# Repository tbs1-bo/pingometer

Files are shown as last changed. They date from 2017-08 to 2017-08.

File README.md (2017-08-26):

Zeigometer
==========

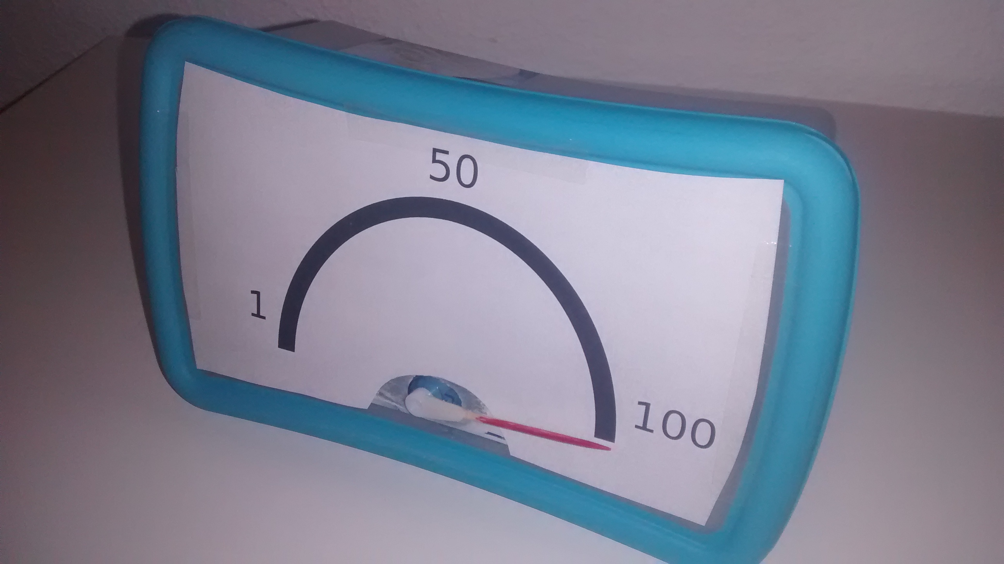
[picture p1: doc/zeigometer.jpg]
zeigometer


The zeigometer is an autonmous device that can show a value on a
scale. It can be made of a an ESP8266, a servo motor, a powerbank or battery and
some housing - I used an ice-cream package for this.

The servo motor is connected to an ESP8266, reads analog values from an
MQTT Broker and  sends the value to a servo that visualizes the value
on a scale. The project is mainly inspired by the
[pingo meter project](https://www.raspberrypi.org/magpi/pingometer/)
from the Raspberry Pi Magazine.

Process Sequence
----------------

Here is what the device actually does.

1. Power on
2. Connect to a pre-configured Wifi-AP
3. Fetch a message from an MQTT Broker from a given topic. The message
   type must be an integer value between 0 and 100. Use retained
   messages when posting to this topic such that the client receives
   older messages.
4. Adjust the needle connected to a servo motor to reflect the value -
   0=left, 100=right.
5. Go into deep sleep for some pre-configured period of time.
6. Awake and start from the beginning.

Sketch
------

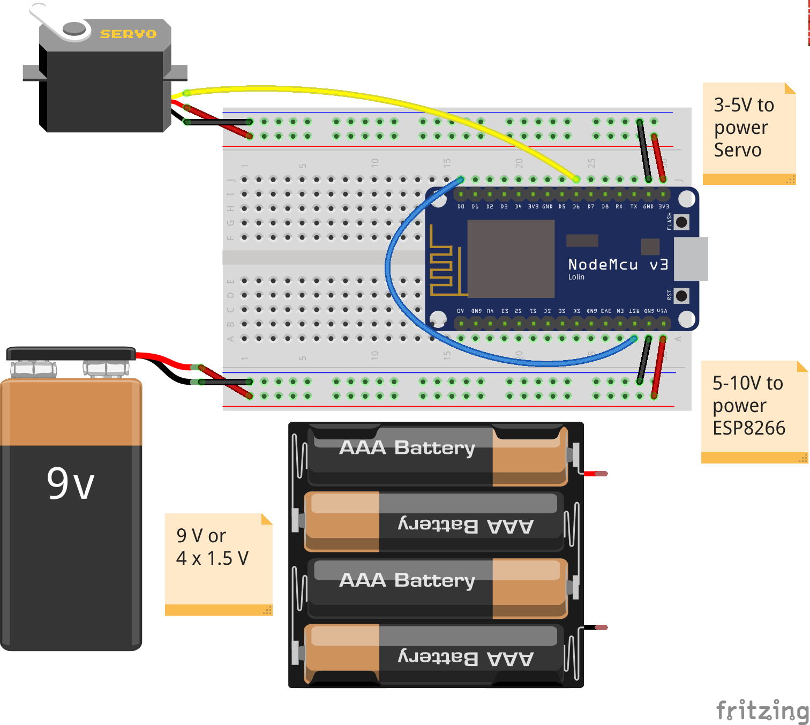
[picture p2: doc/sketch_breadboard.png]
sketch


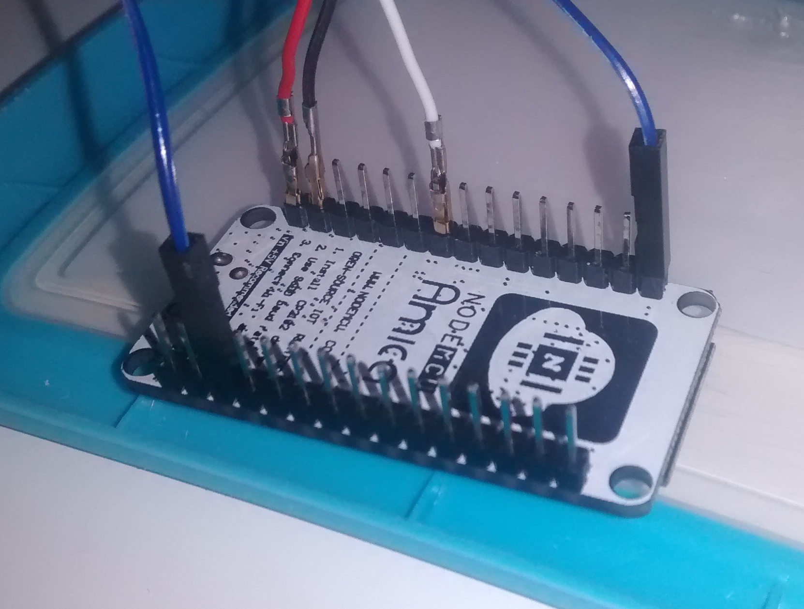
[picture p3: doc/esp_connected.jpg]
esp connected


- The servo is connected to the VCC and Ground for power supply.
- GPIO12 (or what ever is configured) is used as PWM pin for
  controlling the servo.
- GPIO16 and RESET are connected to awake the ESP8266 from deep sleep
  mode. GPIO16 is the only pin that can be used for this purpose.
- Power supply via VIN. Since this pin is controlled by a power
  regulator, up to 10V can be used.

Configuration
-------------

Move [config_sample.py](config_sample.py) to `config.py` and adjust
the values. The file contains comments that explain what the purpose
of the values.

Installation
------------

The ESP8266 needs to be
[flashed with a Micropython firmware](http://docs.micropython.org/en/latest/esp8266/esp8266/tutorial/intro.html#deploying-the-firmware).

Transfer all python files onto the ESP8266. A tool
like [ampy](https://github.com/adafruit/ampy) and
the [deploy.sh](deploy.sh) script will help a lot during this process.

Making
------

The servo is hosted in a plastic ice-cream package. A hole was
drilled to stuff the motor through. The servo itself is glued to the
cover with hot glue.

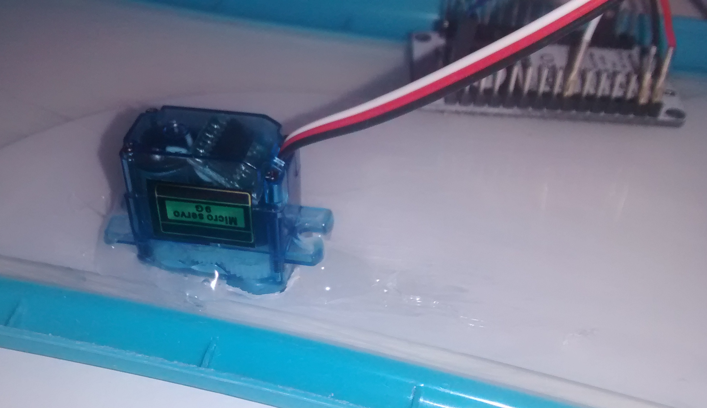
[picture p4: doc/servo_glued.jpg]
servo glued


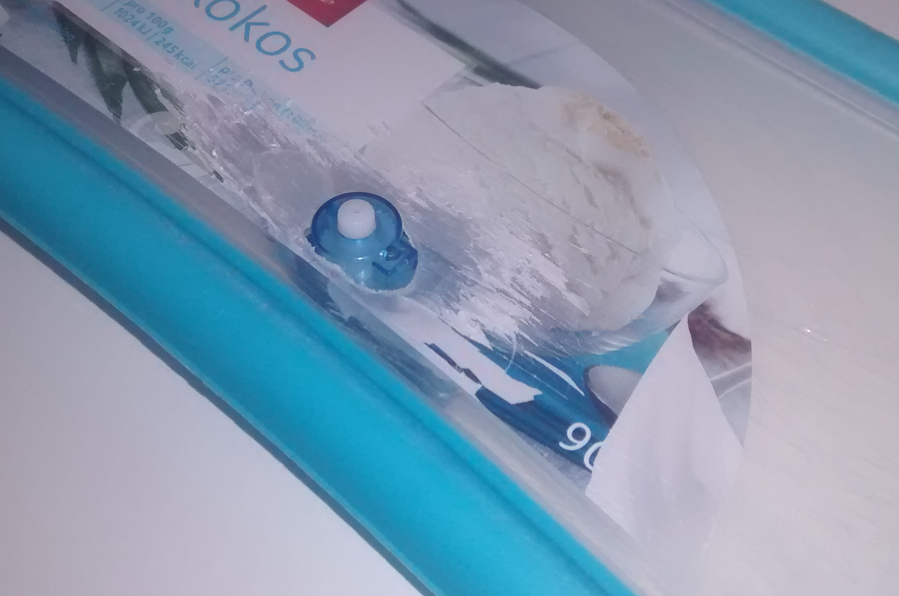
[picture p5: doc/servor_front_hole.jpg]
servo on front hole


Finally a scale is made that hides the shitty cover. Here is
the [template file](doc/scale_template.svg) for this.

zeigometer

Powering
--------

As the the device should work autonomously it still needs some
power. The easiest way to do this would be to use a small
powerbank. However, since the ESP8266 has very low power consumption
of about 20 µA in deep sleep mode, the powerbank may turn itself off
automatically.

The VIN pin of the nocdemcu devkit is connected to a power
regulator. Therefore a single 9V battery or a 4 x 1.5V battery pack
can be attached to power the board.

An
[article at Henry's Bench](http://henrysbench.capnfatz.com/henrys-bench/arduino-projects-tips-and-more/powering-the-esp-12e-nodemcu-development-board/) 
explains different possibilities in powering the nodemci-devkit board.

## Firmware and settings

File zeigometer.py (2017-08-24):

import machine
import network
import time
import socket
import config
import umqtt.simple


class WifiClient:
    def __init__(self, ssid, passwd):
        self.ssid = ssid
        self.passwd = passwd

        # Create and activate station interface
        self.sta_if = network.WLAN(network.STA_IF)
        self.sta_if.active(True)

    def connect(self):
        if not self.sta_if.isconnected():
            print("connecting to", self.ssid)
            self.sta_if.connect(self.ssid, self.passwd)

            # waiting until connected
            while not self.sta_if.isconnected():
                pass

        print("connected with IP", self.sta_if.ifconfig())

    def disconnect(self):
        self.sta_if.disconnect()


class Servo:
    def __init__(self, pin, freq, dc_left, dc_right):
        """Create servo connected with frequency freq to pin. dc_defaults
        contains default duty cylces for values of left and right.
        """

        pin = machine.Pin(pin)
        self.pwm = machine.PWM(pin, freq=freq)
        self.left, self.right = dc_left, dc_right

    def left_right_center(self):
        print("turn left")
        self.change_needle(0)
        time.sleep(1)

        print("turn right")
        self.change_needle(100)
        time.sleep(1)

        print("center")
        self.change_needle(100)
        time.sleep(1)

    def left_to_right(self):
        for rightiness in range(100):
            self.change_needle(rightiness)
            time.sleep(0.5)

    def change_needle(self, rightiness):
        """Change the position of the needle from 0 (left) to 100 (right)."""

        if not 0 <= rightiness <= 100:
            print("ignoring wrong value range")
            return

        delta_lr = self.right - self.left
        dc = self.left + delta_lr * rightiness / 100
        print("change dc to", int(dc))
        self.pwm.duty(int(dc))


class ServoController:
    def __init__(self, host, topic, servo, keepalive=5, qos=1):
        self.topic = topic
        self.host = host
        self.servo = servo
        self.keepalive = keepalive
        self.qos = qos

    def loop_forever(self):
        mqtt = umqtt.simple.MQTTClient('esp123', self.host,
                                       keepalive=self.keepalive)
        mqtt.set_callback(lambda _topic, value:
                          self._change_needle(value))
        print("connecting to MQTT Broker")
        mqtt.connect()
        print("Subscribing to topic", self.topic)
        mqtt.subscribe(self.topic, self.qos)
        print("Awaiting messages from Broker")
        while True:
            mqtt.wait_msg()

    def _change_needle(self, val):
        try:
            newval = int(val)
            self.servo.change_needle(newval)
        except Exception as ex:
            print("Exception occured", ex)


def deepsleep():
    """Go into deep sleep mode. GPIO16 (D0) must be connected to RST
    (RST)."""

    # wait some time before going into deesleep mode - otherwise no
    # intervention possible when problems occur.
    time.sleep(5)
    rtc = machine.RTC()
    rtc.irq(trigger=rtc.ALARM0, wake=machine.DEEPSLEEP)
    # set alarm time (in ms)
    print("setting alarm for RTC", config.DEEPSLEEP_TIME)
    rtc.alarm(rtc.ALARM0, config.DEEPSLEEP_TIME)
    # sleep
    print("starting deep sleep...")
    machine.deepsleep()


def main():
    print("connecting to wifi")
    wifi = WifiClient(ssid=config.SSID, passwd=config.PASS)
    wifi.connect()

    print("starting servo on pin", config.SERVOPIN, "with",
          config.FREQUENCY, "Hz")
    servo = Servo(pin=config.SERVOPIN, freq=config.FREQUENCY,
                  dc_left=config.LEFT, dc_right=config.RIGHT)
    # servo.left_right_center()
    # servo.left_to_right()

    # start timer
    tim = machine.Timer(0)
    print("Timer for deepsleep will elapse in (ms)", config.MAX_UPTIME)
    tim = tim.init(period=config.MAX_UPTIME,
                   mode=machine.Timer.ONE_SHOT,
                   callback=lambda _timer: deepsleep())

    print("Creating servo controller")
    servo_con = ServoController(config.MQTT_HOST, config.MQTT_TOPIC, servo)
    servo_con.loop_forever()


if __name__ == "__main__":
    main()

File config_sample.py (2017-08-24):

# Copy this file to config.py and update the values below.
#

# Network settings to connect the device to.
SSID = "My Network"
PASS = "My Password"

# configure the servo motor
SERVOPIN = 12  # GPIO12 (D6)
FREQUENCY = 50  # Hz

# MQTT host and topic where the value of the needle might come from
MQTT_HOST = 'iot.eclipse.org'
MQTT_TOPIC = 'zeigometer/value'

# maximum runtime (in ms) of the chip before going into deepsleep
MAX_UPTIME = 20000

# how many ms to sleep in deep sleep mode after that amount of time,
# the ESP8266 awakes again. For this to work, pin GPIO16 hat to be
# connected with the RESET Pin.
DEEPSLEEP_TIME = 20000

# common duty cyles that must range from 0 to 1023 and should conform
# to positions of the needle.
LEFT = 25
RIGHT = 125

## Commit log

2017-08-15 created classes WifiClient, Servo
2017-08-16 added sketch.
    [sketch.fzz]
2017-08-16 bugfix deepsleepmode(): constant typo.
    added further config variable DEELSLEEP_TIME.
    [zeigometer.py]
2017-08-16 remove mqtt, switched to http request.
2017-08-16 fix: waiting 1 sec after initial motor calibration.
    [zeigometer.py]
2017-08-16 added servo into operation.
2017-08-16 bugfix: time sleep took too long.
    [zeigometer.py]
2017-08-16 wrong values will be ignored.
    [zeigometer.py]
2017-08-16 small change wiring.
    [sketch.fzz]
2017-08-16 added image of the (near) final device.
2017-08-18 added link to henry bench explaing power supplies.
2017-08-18 added power supply via 9V battery to the sketch. added nodemcu part.
    [sketch.fzz]
2017-08-18 added information about power supply.
2017-08-21 added timer, information about signal strength in topic.
2017-08-24 major change: moved from http request to request to mqtt broker.
    [config_sample.py, zeigometer.py]
2017-08-26 added battery pack to sketch and description.
    [sketch.fzz]
